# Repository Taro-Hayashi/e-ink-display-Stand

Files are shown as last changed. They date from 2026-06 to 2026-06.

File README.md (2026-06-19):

# E-ink APOD Display （[日本語](README_JP.md)）

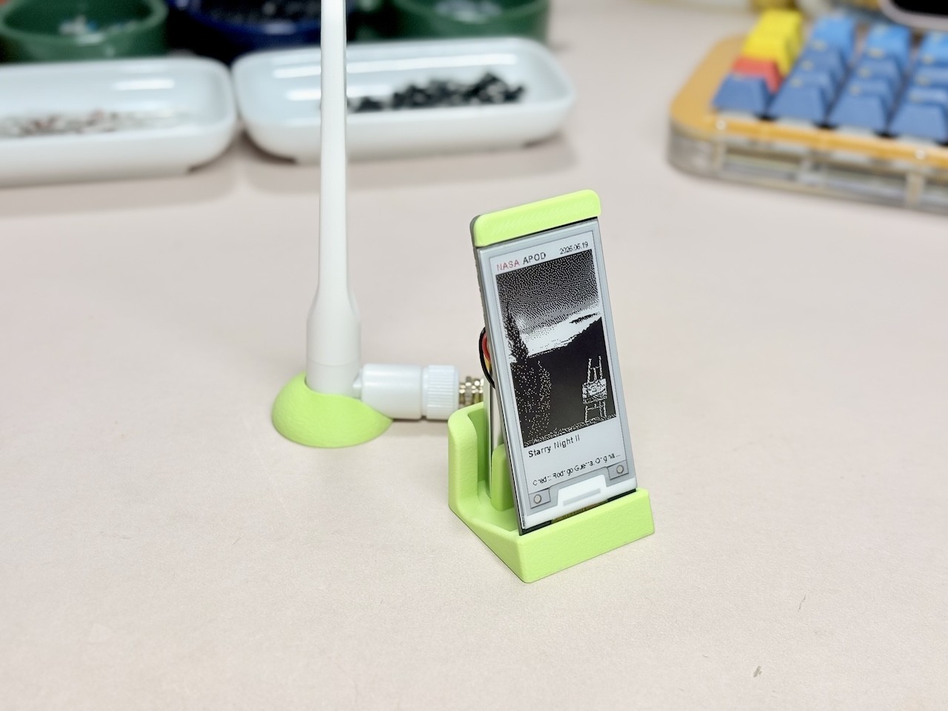
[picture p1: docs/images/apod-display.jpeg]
E-ink APOD Display


A local e-paper display system that fetches NASA Astronomy Picture of the Day (APOD) on a Mac and shows it on a XIAO ESP32C3 with a 2.13-inch three-color e-paper display.  
MakerWorld: [E-ink Display Stand](https://makerworld.com/ja/models/2952512).

- WeAct 2.13-Black-White-Red
- XIAO ESP32C3
- LiPo 602040

## Structure

- `image-render/`: Mac side. Fetches NASA APOD, renders an e-paper image, and serves it over HTTP.
- `xiao-esp32c3-display/`: XIAO ESP32C3 side. Fetches `/apod_image.bin` from the Mac, draws it on the e-paper display, then enters deep sleep for 12 hours.

## Setup Overview

### Mac Side

```bash
cd image-render
python3 -m pip install -r requirements.txt
cp config.example.json config.json
python3 fetch_apod.py
python3 apod_api.py --host 0.0.0.0 --port 8765
```

Endpoints:

- `http://localhost:8765/apod.txt`
- `http://localhost:8765/apod.json`
- `http://localhost:8765/apod_image.png`
- `http://localhost:8765/apod_image.bin`

### XIAO ESP32C3 Side

```bash
cd xiao-esp32c3-display
```

Edit `secrets.h` with your Wi-Fi SSID, password, and the host name or IP address of the Mac running `apod_api.py`, then upload `xiao-esp32c3-display.ino` with the Arduino IDE.

## Ignored Files

- `image-render/config.json`
- `image-render/apod_state.json`
- `image-render/cache/`
- `plasticity-private/`

## 3D Models

Public 3D model files are in `step/`. Use STEP files for editing and dimensional checks, and the 3MF file for slicer import.

Plasticity working files live in `plasticity-private/` and are not included in the public repository.

## License

- Code and documentation: MIT License. See `LICENSE`.
- 3D models under `step/`: CC0 1.0 Universal. See `step/LICENSE`.

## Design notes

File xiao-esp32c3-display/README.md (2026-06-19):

# xiao-esp32c3-display （[日本語](README_JP.md)）

Arduino sketch for showing NASA Astronomy Picture of the Day (APOD) on a XIAO ESP32C3 with a 2.13-inch three-color e-paper display (SSD1680 / GxEPD2_213_Z98c). It fetches `/apod_image.bin` served by `../image-render/apod_api.py` every 12 hours, draws the image, and then enters deep sleep.

## Setup

1. Edit `secrets.h` with your Wi-Fi credentials and Mac-side API host.

```cpp
#define WIFI_SSID "your-wifi-ssid"
#define WIFI_PASSWORD "your-wifi-password"
#define IMAGE_HOST "your-image-host"
#define IMAGE_PORT 8765
#define IMAGE_PATH "/apod_image.bin"
```

2. Select the XIAO ESP32C3 board in the Arduino IDE and upload `xiao-esp32c3-display.ino`.

## Mac Side

First run `fetch_apod.py` in `../image-render/` to create `apod_state.json` and the image cache, then start `apod_api.py --host 0.0.0.0 --port 8765`.

`/apod_image.bin` is a 122x250 black plane plus red plane binary. The sketch reads `EPD_IMAGE_BYTES` bytes from that endpoint.

## Behavior

- Boot -> connect to Wi-Fi -> fetch `/apod_image.bin` -> draw to e-paper -> stop Wi-Fi -> enter deep sleep for 12 hours.
- If fetching fails, the sketch retries once, shows a failure message on the e-paper display, and then enters deep sleep.
- RAM contents are lost during deep sleep.

## Wiring

| Function | XIAO pin | GPIO |
|---|---|---|
| EPD_BUSY | D0 | GPIO2 |
| EPD_RST | D1 | GPIO3 |
| EPD_DC | D2 | GPIO4 |
| EPD_CS | D3 | GPIO5 |
| SPI SCK | D8 | GPIO8 |
| SPI MOSI | D10 | GPIO10 |

## Display Image

The Mac-side `render_apod_image.py` converts the APOD image into a 122x250 black-and-white dithered image and serves small accents on the red plane.

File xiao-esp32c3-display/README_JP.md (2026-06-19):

# xiao-esp32c3-display （[English](README.md)）

XIAO ESP32C3 + 2.13インチ3色電子ペーパー (SSD1680 / GxEPD2_213_Z98c) でNASA Astronomy Picture of the Day (APOD) を表示するArduinoスケッチ。Mac側の `../image-render/apod_api.py` が配信する `/apod_image.bin` を12時間ごとに取得し、描画後に deep sleep する。

## セットアップ

1. `secrets.h` にWi-FiとMac側APIの接続先を設定する。

```cpp
#define WIFI_SSID "your-wifi-ssid"
#define WIFI_PASSWORD "your-wifi-password"
#define IMAGE_HOST "your-image-host"
#define IMAGE_PORT 8765
#define IMAGE_PATH "/apod_image.bin"
```

2. Arduino IDEでXIAO ESP32C3ボードを選択し、`xiao-esp32c3-display.ino` を書き込む。

## Mac側

先に `../image-render/` で `fetch_apod.py` を実行して `apod_state.json` と画像キャッシュを作成し、`apod_api.py --host 0.0.0.0 --port 8765` を起動する。

`/apod_image.bin` は 122x250 の黒プレーンと赤プレーンを連結したデータで、スケッチ側では `EPD_IMAGE_BYTES` 分を読み込む。

## 動作

- 起動 → WiFi接続 → `/apod_image.bin` 取得 → 電子ペーパー描画 → WiFi停止 → 12時間 deep sleep
- 取得に失敗した場合は1回リトライし、失敗メッセージを電子ペーパーへ表示して deep sleep する
- deep sleep中はRAM内容が失われる

## 配線

| 機能 | XIAOピン | GPIO |
|---|---|---|
| EPD_BUSY | D0 | GPIO2 |
| EPD_RST | D1 | GPIO3 |
| EPD_DC | D2 | GPIO4 |
| EPD_CS | D3 | GPIO5 |
| SPI SCK | D8 | GPIO8 |
| SPI MOSI | D10 | GPIO10 |

## 表示画像

Mac側の `render_apod_image.py` が、APOD画像を122x250の白黒ディザ画像へ変換し、一部アクセントだけ赤プレーンとして配信する。

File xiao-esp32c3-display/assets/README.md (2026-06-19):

# assets （[日本語](README_JP.md)）

This directory is not used by the current APOD display version.

APOD images are saved under `../image-render/cache/` on the Mac side and converted for the e-paper display by `../image-render/render_apod_image.py`.

Place fixed logos or boot images here if they are added in the future.

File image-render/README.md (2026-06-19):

# image-render （[日本語](README_JP.md)）

Mac-side scripts for fetching NASA Astronomy Picture of the Day (APOD), rendering an e-paper image, and serving it over HTTP. `fetch_apod.py` downloads APOD metadata and image data, and `apod_api.py` serves the rendered image for the XIAO ESP32C3.

## Files

- `fetch_apod.py`: Fetches APOD metadata and image data from the NASA APOD API, then saves `apod_state.json` and files under `cache/`.
- `apod_api.py`: Serves text, JSON, PNG preview, and packed e-paper binary data.
- `render_apod_image.py`: Renders a 122x250 black/red two-plane image.
- `config.example.json`: Template for `config.json`.
- `requirements.txt`: Python dependencies.

## Setup

```bash
python3 -m pip install -r requirements.txt
cp config.example.json config.json
```

Set your NASA API key in `config.json`. The public sample uses `DEMO_KEY`, but a personal NASA Open APIs key is recommended to avoid shared rate limits.

If you see `HTTP Error 429` or `HTTP Error 503`, the NASA API may be temporarily unavailable or the shared `DEMO_KEY` limit may have been reached. Wait and retry, or set your own NASA API key in `config.json`.

## Run

Fetch APOD:

```bash
python3 fetch_apod.py
```

Fetch a specific date:

```bash
python3 fetch_apod.py --date 2024-04-08
```

Start the HTTP server:

```bash
python3 apod_api.py --host 0.0.0.0 --port 8765
```

## Endpoints

- `http://localhost:8765/apod.txt`
- `http://localhost:8765/apod.json`
- `http://localhost:8765/apod_image.png`
- `http://localhost:8765/apod_image.bin`

`/apod_image.bin` is the black plane plus red plane binary fetched by the XIAO ESP32C3. `/apod_image.png` is a local preview image.

## Image Conversion

APOD images are converted to black-and-white dithering, with small accents such as `NASA` placed on the red plane. If the APOD entry is a video or image fetching fails, the renderer uses a placeholder image.

## Ignored Files

- `config.json`: NASA API key.
- `apod_state.json`: Latest APOD metadata.
- `cache/`: APOD image cache.
- `*.log`, `*.err`, `__pycache__/`

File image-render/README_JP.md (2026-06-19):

# image-render （[English](README.md)）

Mac側で動かすNASA Astronomy Picture of the Day (APOD) 取得・画像生成・HTTP配信用スクリプト群。`fetch_apod.py` がAPODメタデータと画像を取得し、`apod_api.py` がXIAO ESP32C3向けの電子ペーパー画像を配信する。

## ファイル

- `fetch_apod.py`: NASA APOD APIからメタデータと画像を取得し、`apod_state.json` と `cache/` に保存する。
- `apod_api.py`: テキスト、JSON、PNGプレビュー、電子ペーパー用バイナリをHTTP配信する。
- `render_apod_image.py`: 122x250 の黒/赤2プレーン画像を生成する。
- `config.example.json`: `config.json` のテンプレート。
- `requirements.txt`: Python依存関係。

## セットアップ

```bash
python3 -m pip install -r requirements.txt
cp config.example.json config.json
```

`config.json` にはNASA APIキーを設定する。公開サンプルとしては `DEMO_KEY` のまま動作するが、利用制限を避ける場合はNASA Open APIsで取得したキーを指定する。

`HTTP Error 429` や `HTTP Error 503` が出る場合は、NASA API側の一時エラーまたは `DEMO_KEY` の共有制限の可能性がある。少し待って再実行するか、自分のNASA APIキーを `config.json` に設定する。

## 実行

APODを取得:

```bash
python3 fetch_apod.py
```

特定日付を取得:

```bash
python3 fetch_apod.py --date 2024-04-08
```

HTTPサーバーを起動:

```bash
python3 apod_api.py --host 0.0.0.0 --port 8765
```

## エンドポイント

- `http://localhost:8765/apod.txt`
- `http://localhost:8765/apod.json`
- `http://localhost:8765/apod_image.png`
- `http://localhost:8765/apod_image.bin`

`/apod_image.bin` はXIAO ESP32C3が取得する黒プレーン + 赤プレーンの連結データ。`/apod_image.png` はMac上でのレイアウト確認用。

## 画像変換

APOD画像は白黒ディザに変換し、ヘッダーの `NASA` など一部だけ赤プレーンに載せる。APODが動画の日や画像取得に失敗した場合は、プレースホルダー画像を表示する。

## 管理外ファイル

- `config.json`: NASA APIキー。
- `apod_state.json`: 直近のAPODメタデータ。
- `cache/`: APOD画像キャッシュ。
- `*.log`, `*.err`, `__pycache__/`

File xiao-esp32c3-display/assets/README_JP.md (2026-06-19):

# assets （[English](README.md)）

このディレクトリは現在のAPOD表示版では使用しない。

APOD画像はMac側の `../image-render/cache/` に保存され、`../image-render/render_apod_image.py` で電子ペーパー向けに変換される。

将来、固定のロゴや起動画面画像を追加する場合は、このディレクトリに配置する。

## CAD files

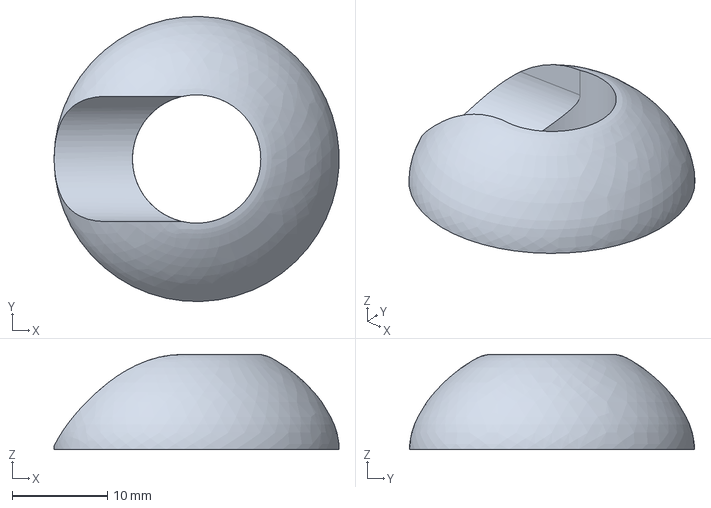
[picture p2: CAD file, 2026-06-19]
step/antenna.stp
30.0 x 30.0 x 10.0 mm

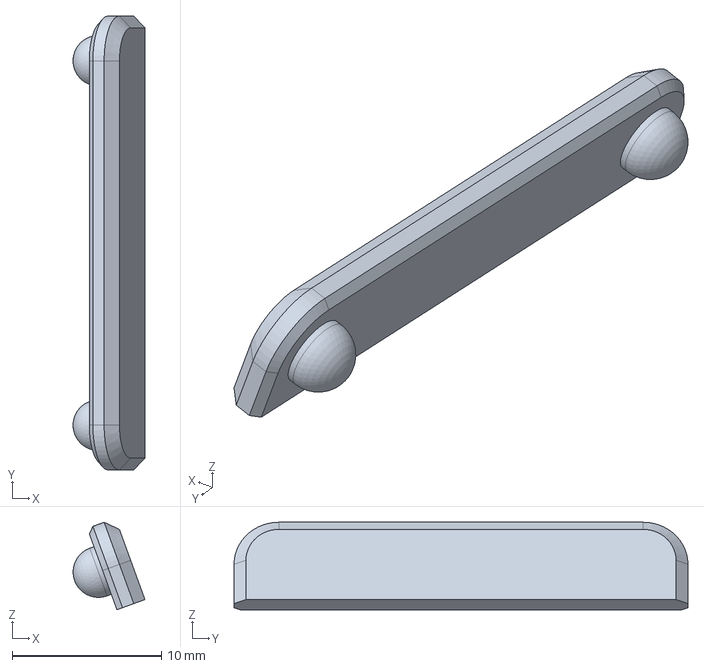
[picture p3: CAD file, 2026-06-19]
step/top.stp
4.82 x 30.4 x 5.86 mm

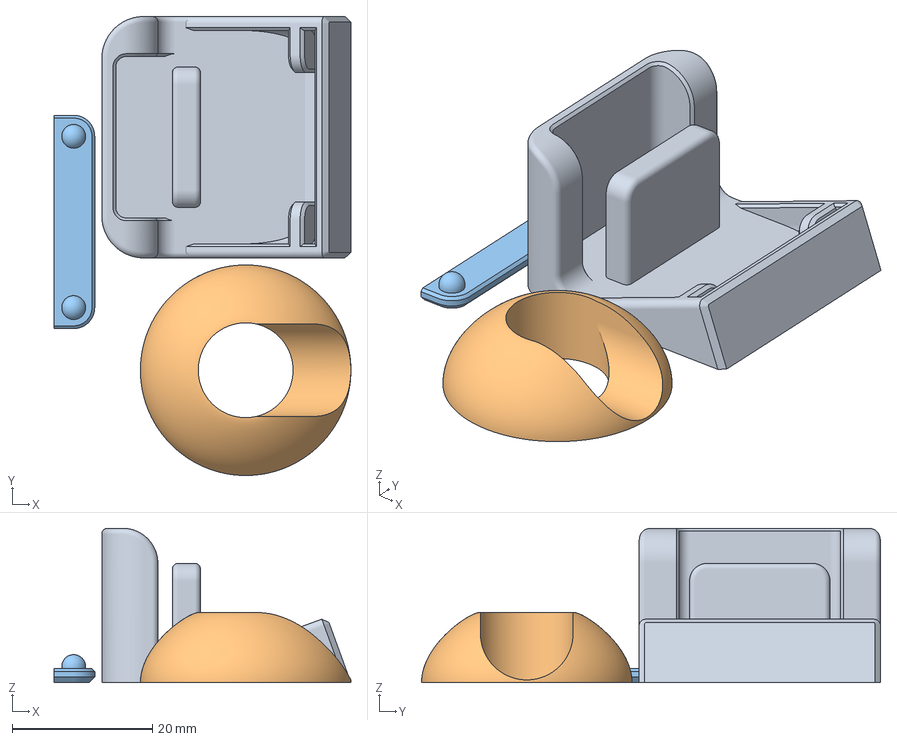
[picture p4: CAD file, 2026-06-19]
step/e-ink-display-stand.3mf
42.3 x 65.4 x 22.0 mm
stand.stp
antenna.stp
top.stp

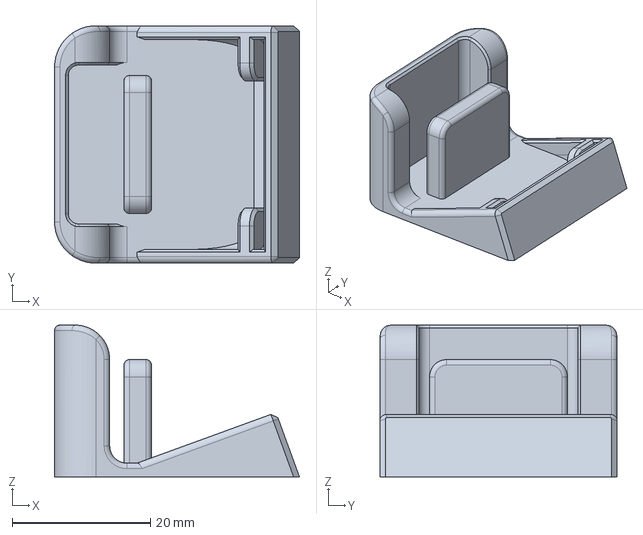
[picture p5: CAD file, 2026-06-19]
step/stand.stp
35.5 x 34.4 x 22.0 mm

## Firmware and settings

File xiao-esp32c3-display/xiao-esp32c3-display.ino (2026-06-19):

#include <GxEPD2_3C.h>
#include <Fonts/FreeMonoBold9pt7b.h>
#include <Fonts/FreeMonoBold12pt7b.h>
#include <WiFi.h>
#include <string.h>
#include <esp_sleep.h>

#include "secrets.h"

// XIAO ESP32C3 pin assignments for e-paper display.
// SPI default pins on XIAO ESP32C3:
//   SCK  = D8  / GPIO8
//   MOSI = D10 / GPIO10
//
// E-paper wiring:
//   EPD VCC  -> 3V3
//   EPD GND  -> GND
//   EPD DIN  -> D10 / MOSI
//   EPD CLK  -> D8  / SCK
//   EPD CS   -> D3
//   EPD DC   -> D2
//   EPD RST  -> D1
//   EPD BUSY -> D0
constexpr int EPD_CS   = D3;
constexpr int EPD_DC   = D2;
constexpr int EPD_RST  = D1;
constexpr int EPD_BUSY = D0;

constexpr int EPD_WIDTH = 122;
constexpr int EPD_HEIGHT = 250;
constexpr int EPD_BYTES_PER_PLANE = ((EPD_WIDTH + 7) / 8) * EPD_HEIGHT;
constexpr int EPD_IMAGE_BYTES = EPD_BYTES_PER_PLANE * 2;

constexpr unsigned long WIFI_TIMEOUT_MS = 45000;
constexpr unsigned long HTTP_BODY_TIMEOUT_MS = 15000;

// Deep sleep duration: 12 hours in microseconds.
constexpr uint64_t SLEEP_DURATION_US = 12ULL * 60ULL * 60ULL * 1000000ULL;

uint8_t blackPlane[EPD_BYTES_PER_PLANE];
uint8_t redPlane[EPD_BYTES_PER_PLANE];
uint8_t imageBytes[EPD_IMAGE_BYTES];

GxEPD2_3C<GxEPD2_213_Z98c, GxEPD2_213_Z98c::HEIGHT> display(
  GxEPD2_213_Z98c(EPD_CS, EPD_DC, EPD_RST, EPD_BUSY)
);

bool readHttpBody(WiFiClient& client, uint8_t* buffer, int expectedBytes) {
  bool headerEnded = false;
  int matched = 0;
  int bytesRead = 0;
  const char marker[] = "\r\n\r\n";
  unsigned long lastRead = millis();

  while (millis() - lastRead < HTTP_BODY_TIMEOUT_MS && bytesRead < expectedBytes) {
    while (client.available() && bytesRead < expectedBytes) {
      char c = client.read();
      lastRead = millis();

      if (!headerEnded) {
        if (c == marker[matched]) {
          matched++;
          if (matched == 4) {
            headerEnded = true;
          }
        } else {
          matched = (c == marker[0]) ? 1 : 0;
        }
      } else {
        buffer[bytesRead++] = static_cast<uint8_t>(c);
      }
    }

    delay(1);
  }

  Serial.print("image bytes read: ");
  Serial.print(bytesRead);
  Serial.print(" / ");
  Serial.println(expectedBytes);

  return bytesRead == expectedBytes;
}

bool fetchDisplayImage() {
  WiFiClient client;

  Serial.println("Connecting to image API...");

  if (!client.connect(IMAGE_HOST, IMAGE_PORT)) {
    Serial.println("image api connect failed");
    return false;
  }

  client.print(String("GET ") + IMAGE_PATH + " HTTP/1.1\r\n");
  client.print(String("Host: ") + IMAGE_HOST + "\r\n");
  client.print("Connection: close\r\n\r\n");

  String statusLine = client.readStringUntil('\n');
  statusLine.trim();

  Serial.print("HTTP status: ");
  Serial.println(statusLine);

  if (!statusLine.startsWith("HTTP/1.1 200") &&
      !statusLine.startsWith("HTTP/1.0 200")) {
    Serial.println("HTTP status not OK");
    client.stop();
    return false;
  }

  bool ok = readHttpBody(client, imageBytes, EPD_IMAGE_BYTES);
  client.stop();

  if (!ok) {
    Serial.println("image read failed");
    return false;
  }

  memcpy(blackPlane, imageBytes, EPD_BYTES_PER_PLANE);
  memcpy(redPlane, imageBytes + EPD_BYTES_PER_PLANE, EPD_BYTES_PER_PLANE);

  return true;
}

bool fetchDisplayImageWithRetry() {
  bool fetched = fetchDisplayImage();

  if (!fetched) {
    Serial.println("image first fetch failed. retrying...");
    delay(1000);
    fetched = fetchDisplayImage();
  }

  if (!fetched) {
    Serial.println("image second fetch failed.");
  }

  return fetched;
}

void drawLines(const String& text) {
  display.setRotation(1);
  display.setFullWindow();

  display.firstPage();

  do {
    display.fillScreen(GxEPD_WHITE);

    display.setTextColor(GxEPD_BLACK);
    display.setFont(&FreeMonoBold9pt7b);

    int16_t y = 18;
    int lineStart = 0;

    while (lineStart < text.length() && y < 122) {
      int lineEnd = text.indexOf('\n', lineStart);

      if (lineEnd < 0) {
        lineEnd = text.length();
      }

      String line = text.substring(lineStart, lineEnd);

      if (line.length() > 26) {
        line = line.substring(0, 23) + "...";
      }

      display.setCursor(8, y);
      display.print(line);

      y += 20;
      lineStart = lineEnd + 1;
    }
  } while (display.nextPage());
}

void drawDisplayImage() {
  display.setRotation(2);
  display.setFullWindow();

  display.firstPage();

  do {
    display.fillScreen(GxEPD_WHITE);

    display.drawImage(
      blackPlane,
      redPlane,
      0,
      0,
      EPD_WIDTH,
      EPD_HEIGHT,
      false,
      false,
      false
    );
  } while (display.nextPage());
}
bool connectWiFiOnce(unsigned long timeoutMs) {
  WiFi.begin(WIFI_SSID, WIFI_PASSWORD);

  unsigned long started = millis();

  while (WiFi.status() != WL_CONNECTED &&
         millis() - started < timeoutMs) {
    Serial.print("Wi-Fi status: ");
    Serial.println(WiFi.status());
    delay(1000);
  }

  return WiFi.status() == WL_CONNECTED;
}

void connectWiFi() {
  WiFi.persistent(false);

  Serial.println("Preparing Wi-Fi.");

  WiFi.mode(WIFI_STA);
  WiFi.setSleep(false);
  delay(500);

  WiFi.disconnect(false);
  delay(500);

  Serial.print("Connecting to Wi-Fi SSID: ");
  Serial.println(WIFI_SSID);

  if (!connectWiFiOnce(30000)) {
    Serial.print("Wi-Fi first attempt failed. status: ");
    Serial.println(WiFi.status());

    WiFi.disconnect(false);
    delay(2000);

    Serial.println("Retrying Wi-Fi...");
    connectWiFiOnce(30000);
  }

  if (WiFi.status() == WL_CONNECTED) {
    Serial.print("Wi-Fi connected. IP: ");
    Serial.println(WiFi.localIP());

    Serial.print("RSSI: ");
    Serial.println(WiFi.RSSI());
  } else {
    Serial.print("Wi-Fi connect failed. Final status: ");
    Serial.println(WiFi.status());
  }
}

void shutdownWiFi() {
  Serial.println("Shutting down Wi-Fi radio.");

  WiFi.disconnect(false);
  delay(300);

  WiFi.mode(WIFI_OFF);
  delay(300);
}


void sleepNow() {
  // Do not call display.hibernate() here.
  // On this e-paper setup it causes the screen to flash and turn white.

  shutdownWiFi();

  Serial.println("Entering deep sleep for 12 hours.");
  Serial.flush();
  delay(100);

  esp_sleep_enable_timer_wakeup(SLEEP_DURATION_US);
  esp_deep_sleep_start();
}

void setup() {
  Serial.begin(115200);
  delay(1000);

  Serial.println();
  Serial.println("Booting XIAO ESP32C3 APOD display");

  SPI.begin();
  // If you want to specify SPI pins explicitly, use this instead:
  // SPI.begin(D8, -1, D10, EPD_CS);

  display.init(115200, true, 20, false);

  drawLines("connecting...");

  connectWiFi();

  if (WiFi.status() != WL_CONNECTED) {
    drawLines(String("wifi\nconnect failed\nstatus: ") + WiFi.status());
    sleepNow();
  }

  if (fetchDisplayImageWithRetry()) {
    drawDisplayImage();
  } else {
    drawLines("apod image\nfetch failed");
  }

  sleepNow();
}

void loop() {
  // Not used.
  // Deep sleep restarts execution from setup().
}
